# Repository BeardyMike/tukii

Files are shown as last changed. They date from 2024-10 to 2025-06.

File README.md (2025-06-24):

# tukii
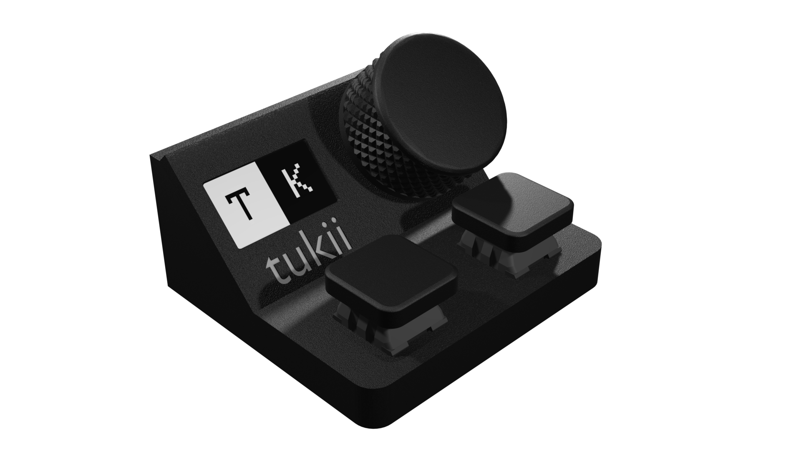
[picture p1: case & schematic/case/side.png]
 
 ### a silly project to make a two button keyboard, blown way past the brief with unneeded features, schematics, 3d print files, and detailed 3d renders.

 ## Why?
 Great Question! 
 I started this project by making a programmable key, the OneKey, as a way to put my programming learning into something tangible. The tukii spawned from it hellish corpse, 
 and my friends and family have allowed this sickness to continue unimpeaded. 

 Starting in Circuit Python, the tukii was feature rich but sluggish and un responsive. Switching to a complete rewrite was the most obvious and time intensive solution I 
 could find.

 The tukii will grow and improve. It is inevitable. There is nothing you can do. It has already started.
 
 ## Components
 Waveshare RP2040 ZERO <br>
 EC11 Rotary Encoder <br>
 Mechanical Switch x 2<br>
 0.96" OLED SSD1306<br>
 <br><br>
 The schematic is easy to reproduce, and features easily sourced components. <br>
 

## Compile and Install
Use the Arduino IDE, using the libraries listed at the top of the .ino file.

## Case
The case, buttons, and dial are all 3d printed. files are included.

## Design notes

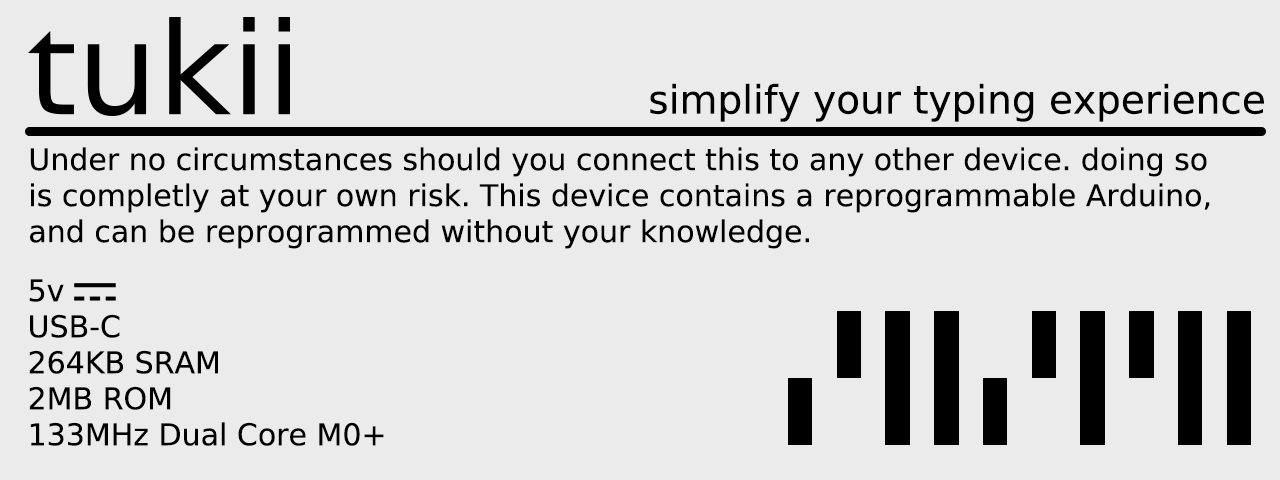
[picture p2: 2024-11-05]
case & schematic/case/Sticker.png

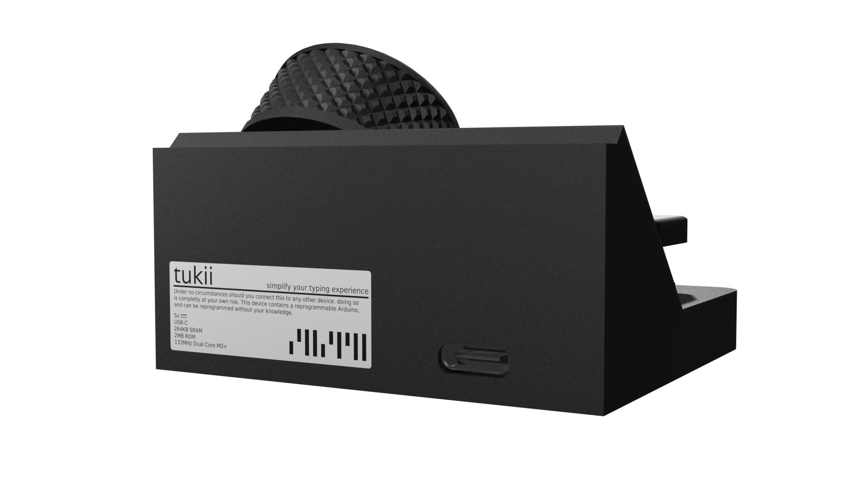
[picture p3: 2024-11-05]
case & schematic/case/back.png

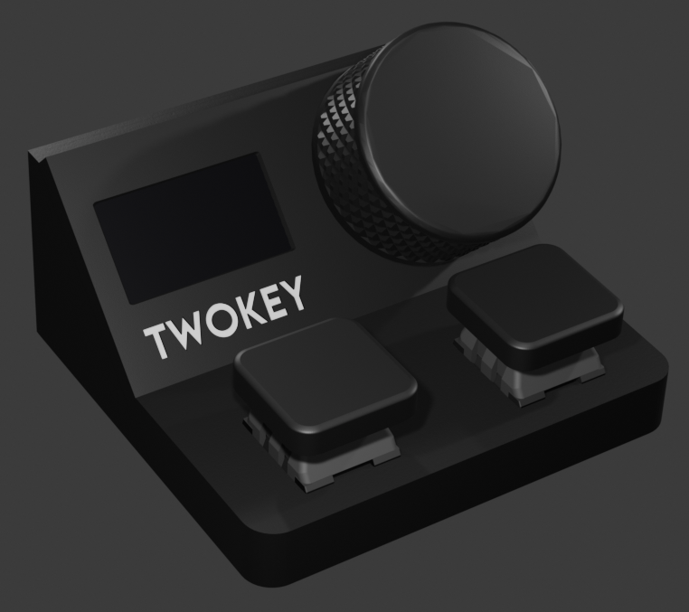
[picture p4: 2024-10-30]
tukii.png

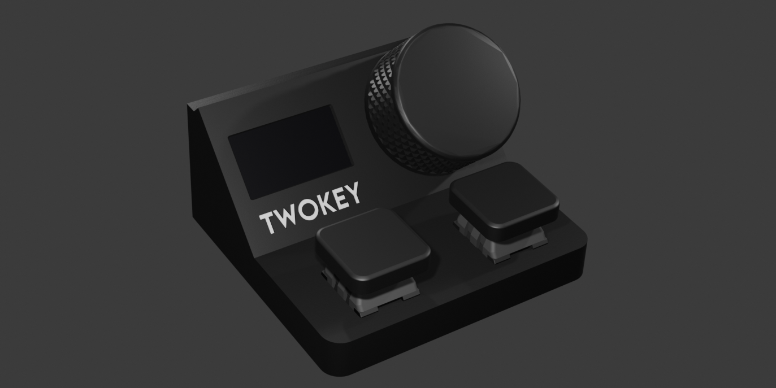
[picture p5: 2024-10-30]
tukii2.png

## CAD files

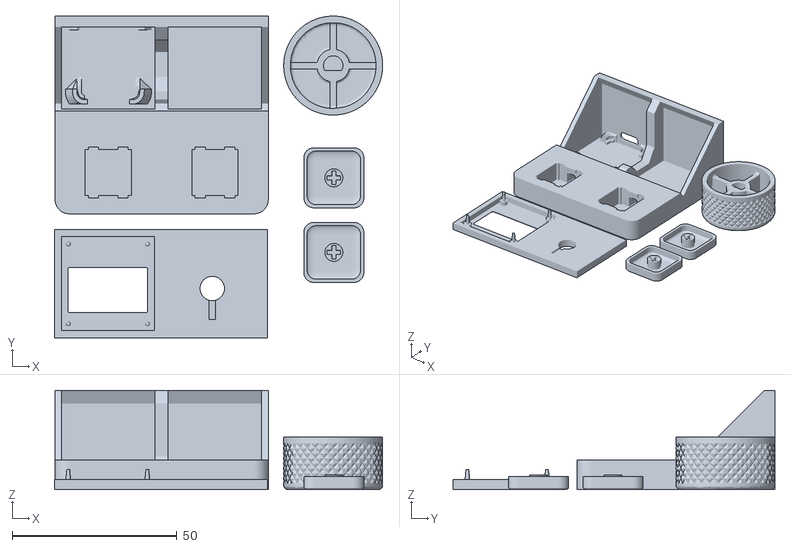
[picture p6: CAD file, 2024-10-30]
case & schematic/case/All Parts.stl
99.5 x 97.6 x 30.1

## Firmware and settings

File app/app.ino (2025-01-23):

/*//|_   _|/////(_) h| (_)/////| (_)/////////| |/(_)/////////////////////////////////////////////////
//    | |  _ __  _| |_ _  __ _| |_ ___  __ _| |_ _  ___  _ __                                      //
//    | | | '_ \| | __| |/ _` | | / __|/ _` | __| |/ _ \| '_ \                                     //
//   _| |_| | | | | |_| | (_| | | \__ \ (_| | |_| | (_) | | | |                                    //
//  |_____|_| |_|_|\__|_|\__,_|_|_|___/\__,_|\__|_|\___/|_| |_|                                    //
///////////////////////////////////////////////////////////////////////////////////////////////////*/
// last edit - 21/01/25
#include <Wire.h>              // github.com/esp8266/Arduino/tree/master/libraries/Wire
#include <Adafruit_GFX.h>      // github.com/adafruit/Adafruit-GFX-Library
#include <Adafruit_SSD1306.h>  // github.com/adafruit/Adafruit-SD1306
#include <RotaryEncoder.h>     // github.com/mathertel/RotaryEncoder
#include <LittleFS.h>
#include <TinyUSB_Mouse_and_Keyboard.h>
#define SCREEN_WIDTH 128
#define SCREEN_HEIGHT 64
#define OLED_RESET -1

/*-------------------------------------------------------------------------------------------------*/

// Pin definitions for buttons
#define button1Pin 28  // Left ButtonAAE94
#define button2Pin 26  // Right Button

/*-------------------------------------------------------------------------------------------------*/

// Define rotary encoder pins
#define ROTARY_ENCODER_A_PIN 3  // Dial Pin A (CCW)
#define ROTARY_ENCODER_B_PIN 2  // Dial Pin B (CW)
#define ROTARY_BUTTON 14        // Dial Switch Pin (BTN)

/*-------------------------------------------------------------------------------------------------*/

// Define important variables outside the scope of functions
const char characters[] = "ABCDEFGHIJKLMNOPQRSTUVWXYZabcdefghijklmnopqrstuvwxyz0123456789";
const char *action_list[] = {
  "copy",
  "paste",
  "cut",
  "undo",
  "redo",
  "selall",
  "save",
  "print",
  "find",
  "replce",
  "tskman",
  "close"
};

/*-------------------------------------------------------------------------------------------------*/

// Define the display
Adafruit_SSD1306 display(SCREEN_WIDTH, SCREEN_HEIGHT, &Wire, OLED_RESET);

/*-------------------------------------------------------------------------------------------------*/

// Initialize the rotary encoder
RotaryEncoder encoder(ROTARY_ENCODER_A_PIN, ROTARY_ENCODER_B_PIN, RotaryEncoder::LatchMode::FOUR3);

/*-------------------------------------------------------------------------------------------------*/

// character screen vars
int ll_index = 60;
int l_index = 61;
int mid_index = 0;
int r_index = 1;
int rr_index = 2;

/*-------------------------------------------------------------------------------------------------*/

// Define or initialise important vars
int pos = 0;
int leftKey;
int leftVal;
int rightKey;
int rightVal;
int dial_still_pressed;
int action;  // 0 = copy, 1 = paste, 2 = cut, 3 = undo, 4 = redo, 5 = selall, 6 = save, 7 = print, 8 = find, 9 = replace, 10 = tskman, 11 = close
bool screen_saver_on_off = false;
uint64_t screen_saver_timer = 0;

/*-------------------------------------------------------------------------------------------------*/

// Define the arkanoid variables
int paddleX = 54;  // Paddle starting position
int ballX = 64, ballY = 32;  // Ball starting position
int ballSpeedX = 1, ballSpeedY = 1;  // Ball speed
bool gameRunning = false;


// text from patorjk.com/software/taag/#p=display&f=Big&t=BeardyMike
// ^ - Init
/////////////////////////////////////////////////////////////////////////////////////////////////////
/////////////////////////////////////////////////////////////////////////////////////////////////////







/*//// ____|////| |//////////////////////////////////////////////////////////////////////////////////
//  | (___   ___| |_ _   _ _ __                                                                    //
//   \___ \ / _ \ __| | | | '_ \                                                                   //
//   ____) |  __/ |_| |_| | |_) |                                                                  //
//  |_____/ \___|\__|\__,_| .__/                                                                   //
//////////////////////////| |//////////////////////////////////////////////////////////////////////*/

void setup() {

  // Initialise the Keyboard and Mouse
  Keyboard.begin();
  Mouse.begin();

  /*-------------------------------------------------------------------------------------------------*/

  // Initialize the buttons
  pinMode(button1Pin, INPUT_PULLUP);
  pinMode(button2Pin, INPUT_PULLUP);
  pinMode(ROTARY_BUTTON, INPUT_PULLUP);

  /*-------------------------------------------------------------------------------------------------*/

  // Initialise the serial port
  Serial.begin(115200);
  delay(100);
  Serial.println("tukiiOS is ready!");

  /*-------------------------------------------------------------------------------------------------*/

  // Initialise LittleFS
  if (!LittleFS.begin()) {
    Serial.println("An error occurred during LittleFS initialization!");
    return;
  }

  // Check if buttons.txt exists
  if (LittleFS.exists("/buttons.txt")) {
    Serial.println("buttons.txt exists.");
  } else {
    // Create buttons.txt and write the default values
    File file = LittleFS.open("/buttons.txt", "w");
    if (!file) {
      Serial.println("Failed to create buttons.txt");
      return;
    }
    file.println("22");
    delay(0.01);
    file.println("1");
    delay(0.01);
    file.println("24");
    delay(0.01);
    file.println("1");
    delay(0.01);
    file.close();
    Serial.println("buttons.txt created with default values.");
  }

  // Read the left and right keys from buttons.txt
  File file = LittleFS.open("buttons.txt", "r");
  if (!file) {
    Serial.println("Failed to open buttons.txt");
    return;
  }

  leftKey = file.parseInt();
  // Serial.println(leftKey);
  delay(0.01);

  leftVal = file.parseInt();
  // Serial.println(leftVal);
  delay(0.01);

  rightKey = file.parseInt();
  // Serial.println(rightKey);
  delay(0.01);

  rightVal = file.parseInt();
  // Serial.println(rightVal);
  delay(0.01);

  file.close();

  /*-------------------------------------------------------------------------------------------------*/

  // Initialize the display, then clear it
  display.begin(SSD1306_SWITCHCAPVCC, 0x3C);  // Address 0x3C for 128x64

  /*-------------------------------------------------------------------------------------------------*/

  main_screen();
}

void setup1() {

}
//
// ^ Setup
/////////////////////////////////////////////////////////////////////////////////////////////////////
/////////////////////////////////////////////////////////////////////////////////////////////////////






/*/|  ____|//////////////| |/(_)/////////////////////////////////////////////////////////////////////
// | |__ _   _ _ __   ___| |_ _  ___  _ __  ___                                                    //
// |  __| | | | '_ \ / __| __| |/ _ \| '_ \/ __|                                                   //
// | |  | |_| | | | | (__| |_| | (_) | | | \__ \                                                   //
// |_|   \__,_|_| |_|\___|\__|_|\___/|_| |_|___/                                                   //
///////////////////////////////////////////////////////////////////////////////////////////////////*/
// Common Functions
void Serial_Instructor()
{
  if (Serial.available() > 0) {
    String command = Serial.readStringUntil('\n');
    if (command.startsWith("TK_") && command.endsWith("_TK")) {
      command = command.substring(3, command.length() - 3);  // Remove TK_ and _TK

      if (command == "main_screen") {
        screen_saver_timer = 0;
        main_screen();
      } else if (command == "main_menu") {
        main_menu();
      } else if (command == "main_menu2") {
        main_menu2();
      } else if (command == "character_menu") {
        character_menu();
      } else if (command == "action_menu") {
        action_menu();
      } else if (command == "games_menu") {
        games_menu();
      } else if (command == "about_screen") {
        about_screen();
      } else if (command == "screen_saver") {
        screen_saver();
      } else {
        Serial.println("Unknown command: " + command);
      }
    }
  }
}

class Arkanoid_target {
public:
  int x, y, width, height;
  int health;

  Arkanoid_target(int x, int y, int width, int height) 
    : x(x), y(y), width(width), height(height), health(2) {}

  void render(Adafruit_SSD1306 &display) {
    if (health == 2) {
      display.fillRect(x, y, width, height, WHITE);  // Solid rectangle
    } else if (health == 1) {
      display.drawRect(x, y, width, height, WHITE);  // Hollow rectangle
    }
  }

  void hit() {
    if (health > 0) {
      health--;
    }
  }

  bool isDestroyed() {
    return health == 0;
  }
};

void drawPaddle() {
  display.fillRect(paddleX, 60, 20, 2, WHITE);  // Reduced paddle height
}

void drawBall() {
  display.drawPixel(ballX, ballY, WHITE);  // Single pixel ball instead of rectangle
}

void updateBall() {
  // Update ball position
  ballX += ballSpeedX;
  ballY += ballSpeedY;

  // Simplified boundary checks
  static int topHitCount = 0;
  if (ballX <= 0 || ballX >= SCREEN_WIDTH-1) ballSpeedX = -ballSpeedX;
  if (ballY <= 0) {
    ballSpeedY = -ballSpeedY;
    topHitCount++;
    if (topHitCount >= 5 && abs(ballSpeedY) < 3) {
      ballSpeedY = (ballSpeedY > 0) ? ballSpeedY + 1 : ballSpeedY - 1;
      topHitCount = 0;  // Reset the counter
    }
  }

  // Check for paddle collision and adjust ball speed
  if (ballY >= 58 && ballY <= 62 && ballX >= paddleX && ballX <= paddleX + 20) {
    ballSpeedY = -ballSpeedY;

    int paddleHitPos = ballX - paddleX;
    if (paddleHitPos < 4) {
      // Ball hits the outer left edge of the paddle
      if (ballSpeedX > 0) {
        ballSpeedX = -ballSpeedX;
      } else {
        ballSpeedX = max(ballSpeedX - 1, -3);
      }
    } else if (paddleHitPos > 6) {
      // Ball hits the outer right edge of the paddle
      if (ballSpeedX < 0) {
        ballSpeedX = -ballSpeedX;
      } else {
        ballSpeedX = min(ballSpeedX + 1, 3);
      }
    } else if (paddleHitPos >= 9 && paddleHitPos <= 11) {
      // Ball hits the center 10% of the paddle
      if (ballSpeedX > 0) {
        ballSpeedX = max(ballSpeedX - 1, 1);
      } else {
        ballSpeedX = min(ballSpeedX + 1, -1);
      }
    }
  }

  // Game over check
  if (ballY >= SCREEN_HEIGHT-1) gameRunning = false;
}

void Arkanoid_game() {
  // Initialize game state
  paddleX = 54;
  ballX = random(0, SCREEN_WIDTH);
  ballY = 55; 
  ballSpeedX = (random(0, 2) == 0) ? 1 : -1;
  ballSpeedY = -1;
  gameRunning = true;
  // Create targets
  const int numTargets = 12;
  Arkanoid_target targets[numTargets] = {
    Arkanoid_target(5, 3, 15, 5),
    Arkanoid_target(25, 3, 15, 5),
    Arkanoid_target(45, 3, 15, 5),
    Arkanoid_target(65, 3, 15, 5),
    Arkanoid_target(85, 3, 15, 5),
    Arkanoid_target(105, 3, 15, 5),
    Arkanoid_target(5, 13, 15, 5),
    Arkanoid_target(25, 13, 15, 5),
    Arkanoid_target(45, 13, 15, 5),
    Arkanoid_target(65, 13, 15, 5),
    Arkanoid_target(85, 13, 15, 5),
    Arkanoid_target(105, 13, 15, 5)
  };

  bool allDestroyed = false;

  // Game loop
  while (gameRunning) {
    display.clearDisplay();

    // Optimized paddle movement
    if (digitalRead(button1Pin) == LOW) {
      paddleX = max(0, paddleX - 3);  // Increased speed, using max instead of constrain
    }
    if (digitalRead(button2Pin) == LOW) {
      paddleX = min(108, paddleX + 3);  // Increased speed, using min instead of constrain
    }

    updateBall();

    // Check for collisions with targets
    for (int i = 0; i < numTargets; i++) {
      if (!targets[i].isDestroyed() && ballX >= targets[i].x && ballX <= targets[i].x + targets[i].width &&
          ballY >= targets[i].y && ballY <= targets[i].y + targets[i].height) {
        targets[i].hit();
        ballSpeedY = -ballSpeedY;
      }
    }

    // Draw targets
    for (int i = 0; i < numTargets; i++) {
      targets[i].render(display);
    }

    drawPaddle();
    drawBall();
    display.display();

    // Check if all targets are destroyed
    bool allDestroyed = true;
    for (int i = 0; i < numTargets; i++) {
      if (!targets[i].isDestroyed()) {
        allDestroyed = false;
        break;
      }
    }

    if (allDestroyed) {
      gameRunning = false;
    }

    // Quick exit check
    if (digitalRead(ROTARY_BUTTON) == LOW) {
      while (digitalRead(ROTARY_BUTTON) == LOW);
      screen_saver_timer = 0;
      return main_screen();
    }
  }

  // Game complete screen
  if (allDestroyed) {
    display.clearDisplay();
    display.setTextSize(2);
    display.setTextColor(WHITE);
    display.setCursor(10, 25);
    display.print("Well Done");
    display.display();
    delay(1000);  // Reduced delay
  } else {
    // Quick game over screen
    display.clearDisplay();
    display.setTextSize(2);
    display.setTextColor(WHITE);
    display.setCursor(10, 25);
    display.print("Game Over");
    display.display();
    delay(500);  // Reduced delay
  }
  screen_saver_timer = 0;
  main_screen();

  // Game loop
  while (gameRunning) {
    display.clearDisplay();

    // Optimized paddle movement with speed increase
    static unsigned long lastButtonPressTime = 0;
    static int paddleSpeed = 1;

    if (digitalRead(button1Pin) == LOW) {
      unsigned long currentTime = millis();
      if (currentTime - lastButtonPressTime > 400) {  // Increase speed every 500ms
      paddleSpeed = min(paddleSpeed + 1, 3);  // Max speed is 3
      lastButtonPressTime = currentTime;
      }
      paddleX = max(0, paddleX - paddleSpeed);
    } else if (digitalRead(button2Pin) == LOW) {
      unsigned long currentTime = millis();
      if (currentTime - lastButtonPressTime > 400) {  // Increase speed every 500ms
      paddleSpeed = min(paddleSpeed + 1, 3);  // Max speed is 3
      lastButtonPressTime = currentTime;
      }
      paddleX = min(108, paddleX + paddleSpeed);
    } else {
      paddleSpeed = 1;  // Reset speed when button is released
    }

    updateBall();
    drawPaddle();
    drawBall();
    display.display();

    // Quick exit check
    if (digitalRead(ROTARY_BUTTON) == LOW) {
      while (digitalRead(ROTARY_BUTTON) == LOW);
      screen_saver_timer = 0;
      return main_screen();
    }
  }
}

void press_button(int val) {
  if (val == 0) {
    Keyboard.print(characters[leftKey]);
    while (digitalRead(button1Pin) == LOW) {
      delay(10);
    }
  } else if (val == 1) {
    Keyboard.print(characters[rightKey]);
    while (digitalRead(button2Pin) == LOW) {
      delay(10);
    }
  }
  return;
}

/*-------------------------------------------------------------------------------------------------*/

void action_press(int action) {
  while (digitalRead(button1Pin) == LOW || digitalRead(button2Pin) == LOW) {
    delay(10);
  }

  struct KeyAction {
    const uint8_t modifiers[3];
    uint8_t modifierCount;
    uint8_t key;
  };

  const KeyAction actions[] = {
    { { KEY_LEFT_CTRL }, 1, 'c' },                      // Copy
    { { KEY_LEFT_CTRL }, 1, 'v' },                      // Paste
    { { KEY_LEFT_CTRL }, 1, 'x' },                      // Cut
    { { KEY_LEFT_CTRL }, 1, 'z' },                      // Undo
    { { KEY_LEFT_CTRL }, 1, 'y' },                      // Redo
    { { KEY_LEFT_CTRL }, 1, 'a' },                      // Select All
    { { KEY_LEFT_CTRL }, 1, 's' },                      // Save
    { { KEY_LEFT_CTRL }, 1, 'p' },                      // Print
    { { KEY_LEFT_CTRL }, 1, 'f' },                      // Find
    { { KEY_LEFT_CTRL }, 1, 'h' },                      // Replace
    { { KEY_LEFT_CTRL, KEY_LEFT_SHIFT }, 2, KEY_ESC },  // Task Manager
    { { KEY_LEFT_ALT }, 1, KEY_F4 }                     // Close
  };

  if (action >= 0 && action < (sizeof(actions)/sizeof(actions[0]))) {
    const KeyAction &ka = actions[action];
    for (uint8_t i = 0; i < ka.modifierCount; i++) {
      Keyboard.press(ka.modifiers[i]);
    }
    Keyboard.press(ka.key);
    delay(100);
    Keyboard.releaseAll();
  }
}

/*-------------------------------------------------------------------------------------------------*/

void write_buttons_char(int Lkey, int Lval, int Rkey, int Rval) {
  File file = LittleFS.open("/buttons.txt", "w");
  if (!file) {
    Serial.println("Failed to open buttons.txt");
    return;
  }
  file.println(Lkey);
  delay(0.01);
  file.println(Lval);
  delay(0.01);
  file.println(Rkey);
  delay(0.01);
  file.println(Rval);
  delay(0.01);
  file.close();
  return;
}

/*-------------------------------------------------------------------------------------------------*/


void display_menu(int menuNum, int selected, const String menuItems[], const int cursorX[], const int cursorY[], int numItems) {
  display.clearDisplay();
  display.setTextSize(1);
  display.setTextColor(WHITE);
  display.setCursor(2, 1);
  if (menuNum == 1) {
    display.print("Menu 1/2");
  } else {
    display.print("Menu 2/2");
  }

  for (int i = 0; i < numItems; i++) {
    if (i == selected) {
      if (i >= 2) {
        display.fillRect(cursorX[i] - 1, cursorY[i] - 1, 70, 10, WHITE);
        display.setTextColor(BLACK);
        display.setTextSize(1);
      } else {
        display.fillRect(0, cursorY[i] - 1, 128, 17, WHITE);
        display.setTextColor(BLACK);
        display.setTextSize(2);
      }
    } else {
      display.setTextColor(WHITE);
      if (i >= 2) {
        display.setTextSize(1);
      } else {
        display.setTextSize(2);
      }
    }
    display.setCursor(cursorX[i], cursorY[i]);
    display.print(menuItems[i]);
  }
  display.display();
}

// ^ - Common Functions
/////////////////////////////////////////////////////////////////////////////////////////////////////
/////////////////////////////////////////////////////////////////////////////////////////////////////
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
void loop() {
  Serial_Instructor();
  
  // Helper function to handle button press and rotation
  auto handleButtonPress = [&](int buttonPin, int &key, int &val, int buttonIndex) {
    if (digitalRead(buttonPin) == LOW) {
      int initialPos = encoder.getPosition();
      bool hasRotated = false;
      while (digitalRead(buttonPin) == LOW) {
        delay(25);
        int currentPos = encoder.getPosition();
        int delta = currentPos - initialPos;

        if (delta != 0) {
          hasRotated = true;
          if (val == 1) {
            key = (key + delta + 62) % 62;
            screen_saver_timer = 0;
            main_screen();
          } else if (val == 0) {
            key = (key + delta + 12) % 12;
            screen_saver_timer = 0;
            main_screen();
          }
          
          initialPos = currentPos;
        }
        if (screen_saver_on_off == true) {
          screen_saver_on_off = false;
        screen_saver_timer = 0;
        main_screen();
        } 
        
      }

      if (!hasRotated) {
        if (val == 1) {
          press_button(buttonIndex);
        } else {
          action_press(key);
        }
      } else {
        write_buttons_char(leftKey, leftVal, rightKey, rightVal);
      }
      screen_saver_timer = 0;
    }
  };

  // Handle left and right button presses
  handleButtonPress(button1Pin, leftKey, leftVal, 0);
  handleButtonPress(button2Pin, rightKey, rightVal, 1);

  // Handle rotary button press
  if (digitalRead(ROTARY_BUTTON) == LOW) {
    delay(100);
    if (dial_still_pressed == 0) {
      main_menu();
    }
    dial_still_pressed = 1;
  }
  dial_still_pressed = 0;

  // Handle encoder scroll
  if (digitalRead(button1Pin) == HIGH && digitalRead(button2Pin) == HIGH && digitalRead(ROTARY_BUTTON) == HIGH) {  
    int newPos = encoder.getPosition();
    int delta = newPos - pos;

    if (delta != 0) {
      Mouse.move(0, 0, delta * 1);
      pos = newPos;
      if (screen_saver_on_off == true) {
        screen_saver_on_off = false;
      screen_saver_timer = 0;
      main_screen();
      }  
    screen_saver_timer = 0;
    }
  }
  // Increment screen_saver_timer
  screen_saver_timer++;
  //Serial.println(screen_saver_timer);

  // Check if screen_saver_timer has reached 42,857,143 which is roughly 5 minutes, 1 minute would be roughly 8,571,429.
  if (screen_saver_timer >= 42857143) {
    screen_saver();
  }

}

// loop for CPU 1
void loop1(){
    encoder.tick();
}
//
// ^ Loop
/////////////////////////////////////////////////////////////////////////////////////////////////////
/////////////////////////////////////////////////////////////////////////////////////////////////////

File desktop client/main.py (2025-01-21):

##################################################################################
#                                                                                #
#   This is the companion app for the tukii:DE. This app reads data from the     #
#   tukii and performs the actions, communication happens over the serial bus.   #
#   The tukii uses TinyUSB. Configuring the tukii from the app will send the     #
#   new config via TinyUSB, and also to the webserver, so the user config can    #
#   be saved and applied as needed. Profiles can also be made and applied using  #
#   the app. Profiles are loaded to the tukii over TinyUSB.   
# 
#   The app connects to the BeardyMike API server to get the latest weather and  #
#   crypto data, which will be sent to the tukii and shown on the screensaver.   #
#   The user needs to enter their API key to enable this feature, as the server  #
#   is restricted, and the user needs to be authenitcated.                       #
#                                                                                #
#   @Author: BeardyMike                                                          #
#                                                                                #
##################################################################################



##################################################################################
# import modules

# pip install customtkinter
import customtkinter
import serial
import serial.tools.list_ports

# pip install pystray
import pystray
import os
from PIL import Image
import configparser
import threading
import time

# Set the working directory to the directory the script is running from
os.chdir(os.path.dirname(os.path.abspath(__file__)))
##############################################################################



##############################################################################
# Global variables

# temp variable to store the previous event for the hover function
temp = ""

# Define the image for the system tray icon
image = Image.open("data/image/logo.ico")

# Set the size of the main app window
gui_X = 650
gui_Y = 450
gui_sidebar_width = 140
gui_main_frame_width = gui_X - gui_sidebar_width

# Images
tray_icon = "data/image/logo.ico"
lcd_image = "data/image/lcd.png"
logo_image = "data/image/logo.ico"
tukii_image = "data/image/img.png"

# file paths
data_ini = "data/data.ini"

# Load custom font
customtkinter.FontManager.load_font("data/Ardy.ttf")

##############################################################################



##############################################################################
# Functions and Commands

# Function to compare the current event to the previous event.
def compare(event, temp):
    return event == temp

# Function to print to the console when a button is hovered over.
# add -->    .bind("<Enter>", lambda eff: on_hover(eff="None", event="Button Name"), add='+')     <-- to something to call this function
def on_hover(eff="None", event=""):
    global temp
    if compare(event, temp) == True:
        return
    print("Hovering over " + event)
    temp = event
    return

# Function to quit the app, called when the Quit option is selected from the system tray icon menu.
def quit_window():
    icon.stop()
    app.quit()

# Function to hide the window, called when the window is closed.
def withdraw_window():
    app.withdraw()

# Function to toggle the window, called when the .Starter option is chosen from the system tray.
def toggle_window():
    if app.state() == "withdrawn":
        app.deiconify()
    else:
        app.withdraw()

def ini_write(section, key, value):
    config = configparser.ConfigParser()
    config.read(data_ini)
    config.set(section, key, value) 
    with open(data_ini, 'w') as configfile:
        config.write(configfile)

customtkinter.set_appearance_mode("System")  # Modes: "System" (standard), "Dark", "Light".
customtkinter.set_default_color_theme("dark-blue")  # Themes: "blue" (standard), "green", "dark-blue".
main_frame_colour = ("#EBEBEB","#1A1A1A") # https://www.google.com/search?q=%23ebebeb & https://www.google.com/search?q=%231a1a1a


##############################################################################



##############################################################################
# Classes

# This class will be the main app window.
class App(customtkinter.CTk):
    def __init__(self):
        super().__init__()

        customtkinter.deactivate_automatic_dpi_awareness()

        def page1_button():
            print("Home Button Pressed")
            self.main_frame.destroy()
            self.main_frame = Page1Frame(self)
            ini_write("main", "active_page", "1")

        def page2_button():
            print("L+R Button Pressed")
            self.main_frame.destroy()
            self.main_frame = Page2Frame(self)
            ini_write('main', 'active_page', "2") 
           
        def page3_button():
            print("Actions Button Pressed")
            self.main_frame.destroy()
            self.main_frame = Page3Frame(self)
            ini_write('main', 'active_page', "3") 
   
        def page4_button():
            print("Screensaver Button Pressed")
            self.main_frame.destroy()
            self.main_frame = Page4Frame(self)
            ini_write('main', 'active_page', "4") 
       
        def page5_button():
            print("Account Button Pressed")
            self.main_frame.destroy()
            self.main_frame = Page5Frame(self)
            ini_write('main', 'active_page', "5") 
        # Configure window
        self.title("")
        self.resizable(False, False)
           
        # Configure grid layout (4x4).
        self.grid_columnconfigure(0, weight=0)
        self.grid_columnconfigure(1, weight=1)
        self.grid_rowconfigure(0, weight=1)
        
        # Create sidebar frame with widgets.
        self.sidebar_frame = customtkinter.CTkFrame(self, width=gui_sidebar_width , corner_radius=0)
        self.sidebar_frame.grid(row=0, column=0, rowspan=6, sticky="nsew")
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

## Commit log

2024-10-30 supporting docs
    [All Parts.stl, tukii.fzz]
2024-11-01 function refactoring
    v1.01
    Functions have been refactored, as they no longer need to be so easy to read.
    [app.ino]
2024-11-05 main menu rotation debounce
    added a 500ms delay after the dial button has been released, as users are rotating the dial slightly when clicking it.
2024-11-05 Main Menu dial input debounce
    500ms delay reduced to 250ms. 500 was too much, 250 feels much better.
    [app.ino]
2024-11-05 Blender and Render Update
    new blender materials and simplified material rendering
2024-11-07 3D model updated
    3D Model is now vastly improved. Material and Environment. 7z'd the blend file as its over 100mb now.
2025-01-21 dualcore mode enabled
    using the second CPU core, the rotary encoder has been super charged!
2025-01-23 screen saver timer
    added the screensaver timer and checks
